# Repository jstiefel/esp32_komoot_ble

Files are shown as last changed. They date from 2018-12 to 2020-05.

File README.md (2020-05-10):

Hint: The code is deprecated and only kept for reference. Only tested with iOS. It won't work if you don't use the mentioned library versions. The official ESP32 Android libraries now include BLE.

# The Komoot BLE Navigation Device Project

The goal of this project is to create an inexpensive turn-by-turn navigation device based on ESP32 and [Komoot's BLE Connect API](https://github.com/komoot/BLEConnect).

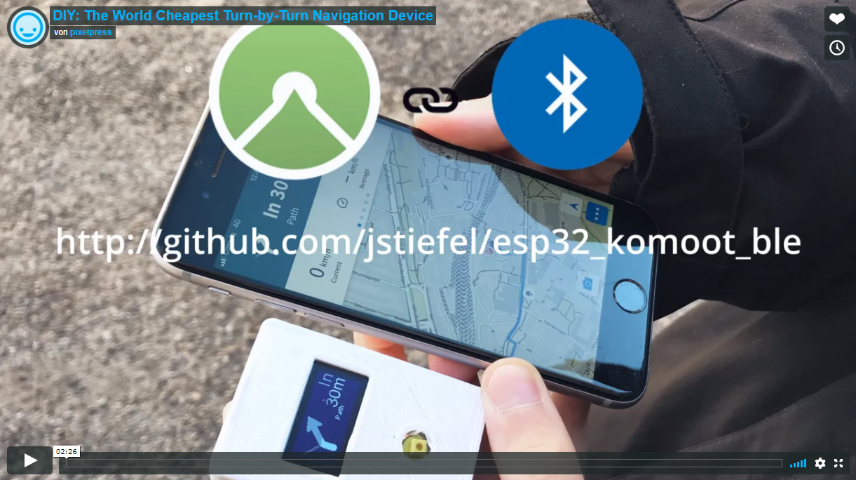
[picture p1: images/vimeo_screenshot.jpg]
DIY: The World Cheapest Turn-by-Turn Navigation Device (https://vimeo.com/308569903 "DIY: The World Cheapest Turn-by-Turn Navigation Device - Click to Watch!")


## Overview

This repository includes all the necessary files to build your own turn-by-turn navigation device including the files for the 3D printable case.

## User instructions
1. The battery can easily be charged by connecting the ESP32 to an USB charger if a controller with battery management is used (e.g. Adafruit Huzzah ESP32).
2. To wake up the device from deep sleep press the button. The welcome screen is shown and ESP32 starts searching for the Komoot BLE service.
3. Open the [Komoot app](https://www.komoot.de/) on your phone and make sure Bluetooth on your phone is turned on. Start your navigation. There is no need to manually connect the ESP32 in the settings. After some seconds, the devices are paired.
4. The device now shows the navigation instructions from the Komoot app. 
5. If connection is lost or navigation stopped, ESP32 tries to keep connection to the device for first 100 seconds. After this, it starts searching for new devices. If no new device is found for the next 100 seconds, it returns to deep sleep.
6. Device can manually be turned off by pushing the button. This takes approximately 2 seconds.

## Status

This is a first prototype which is fully working and tested. New functionality and hardware may be added. The ESP32 is quite new and the Arduino implementation still undergoing many changes. It is recommended to use the same release as stated here because there were many issues with BLE when updating versions.

Next steps:

- improve case/ make smaller
- use larger display
- smoothen images
- add more functionality
- add battery indication
- continuously update used libraries

## Hints

- Device can not be completely turned off without disconnecting battery, but we can enter deep sleep by pushing button and waking up again by pushing same button
- Device can be loaded over USB port (LiPo control on-board)
- Rename main file in .ino to work with Arduino IDE

## Hardware

- Adafruit Huzzah ESP32 (or any other with included battery management)
- 128x64 OLED, SSD1306 Controller
- Push button, some wires and 3D printed case, screws
- 3.7V 400mAh LiPo

## Connections

Display:

| Display | ESP32 |
|---|---|
|SDA|Pin 27|
|SCL|Pin 33|
|VCC|VCC|
|GND|GND|

Button:

| Button | ESP32 |
|---|---|
|In|Pin 32 pulled down with 10kOhm resistor connected to GND|
|Out|VCC|

## Dependencies

- [ESP8266 and ESP32 Oled Driver for SSD1306 display 4.0.0 by Daniel Eichhorn, Fabrice Weinberg](https://github.com/ThingPulse/esp8266-oled-ssd1306)
- [Arduino core for ESP32 WiFi chip v1.0.1-rc1](https://github.com/espressif/arduino-esp32) (development release)
- Replace BLE source code in /opt/eclipse/arduinoPlugin/packages/esp32/hardware/esp32/1.0.1-rc1/libraries/BLE/src by commit _11a0aa6_ of [ESP32_BLE_Arduino](https://github.com/nkolban/ESP32_BLE_Arduino)
- Developped in Eclipse with [Sloeber](https://github.com/Sloeber/arduino-eclipse-plugin)

## Assembly

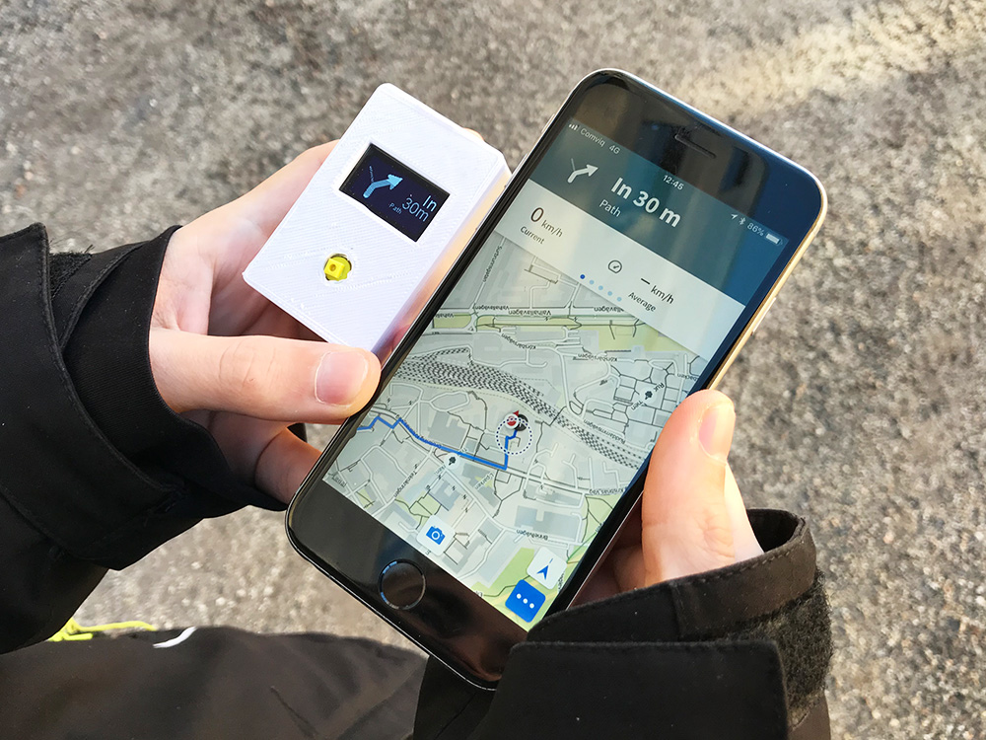
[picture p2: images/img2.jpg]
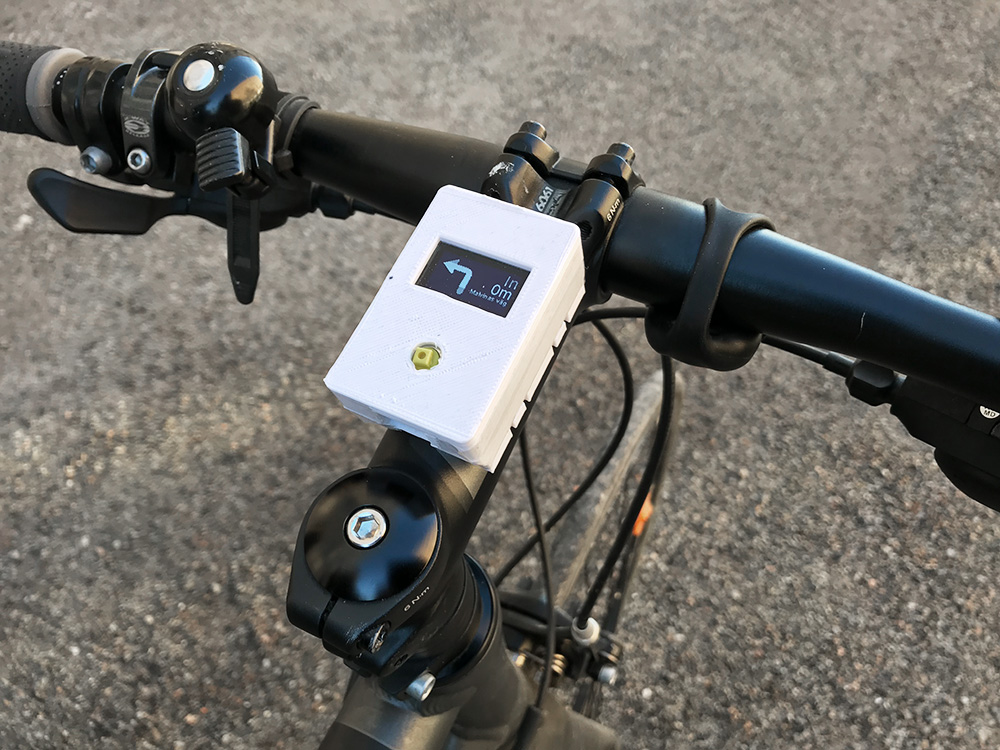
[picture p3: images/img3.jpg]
  <br/>

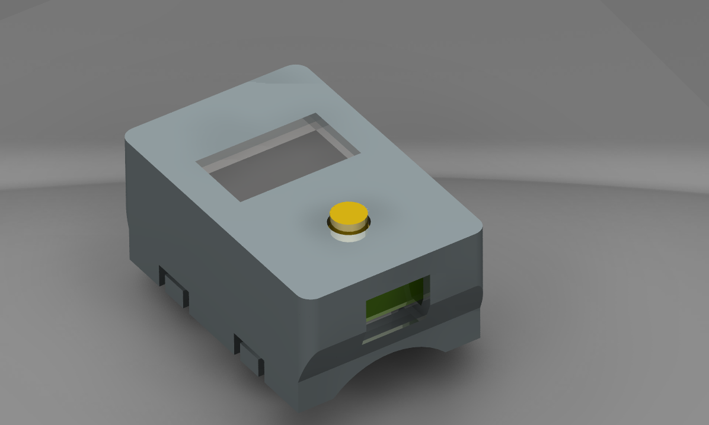
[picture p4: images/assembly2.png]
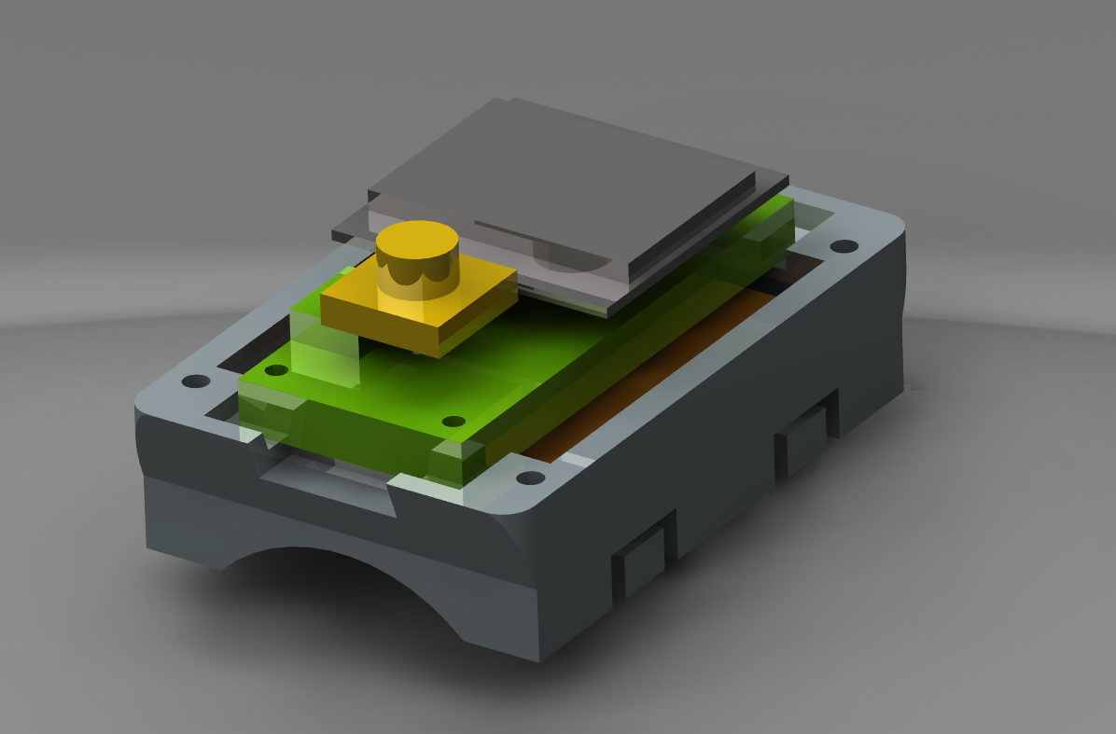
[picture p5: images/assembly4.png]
  <br/>

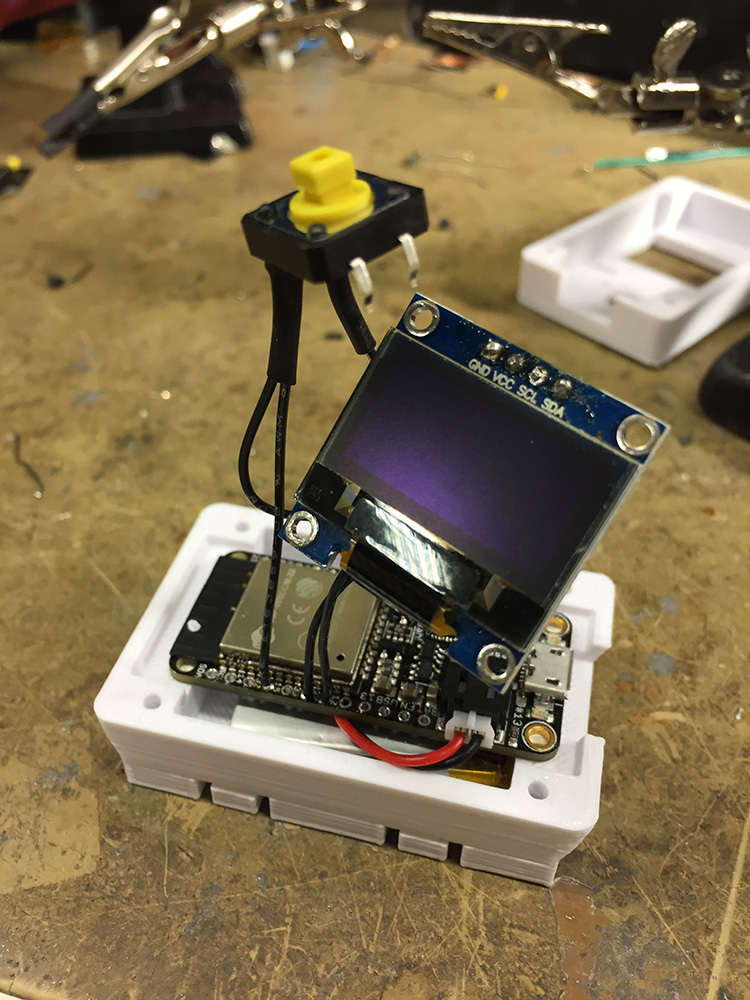
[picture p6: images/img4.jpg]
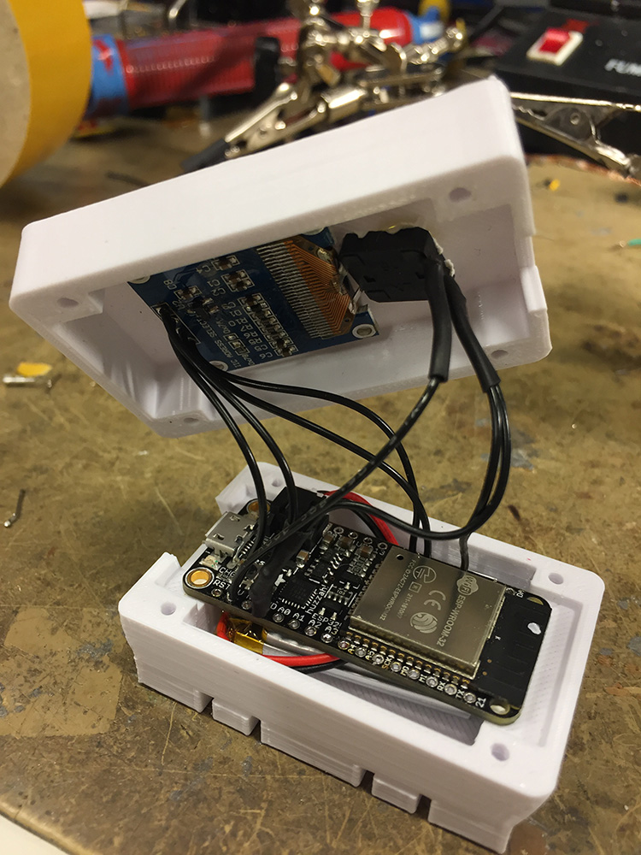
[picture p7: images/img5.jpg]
  

## Credits
- @danielgard for clarifying some things about the Komoot API
- @chegewara for continuously debugging Arduino ESP32 BLE
- Axel Poidevin for carrying the bike and phone in the video

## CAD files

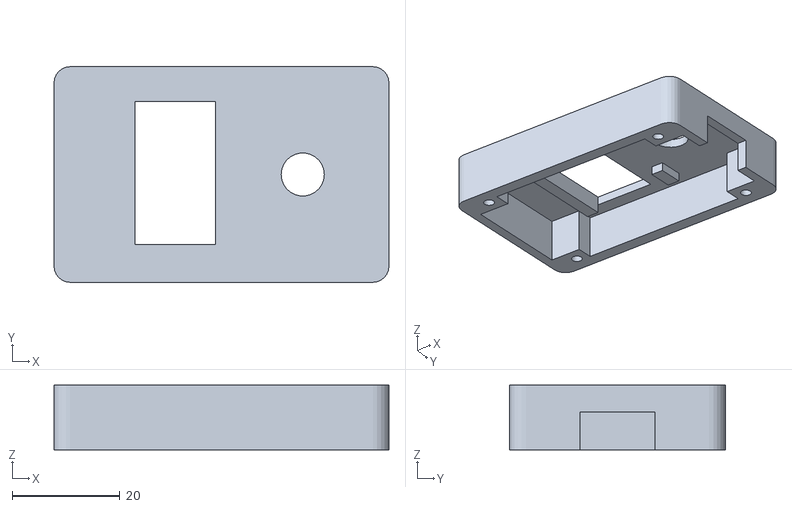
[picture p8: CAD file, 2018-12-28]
CAD/top.stl
62.1 x 40.0 x 12.0

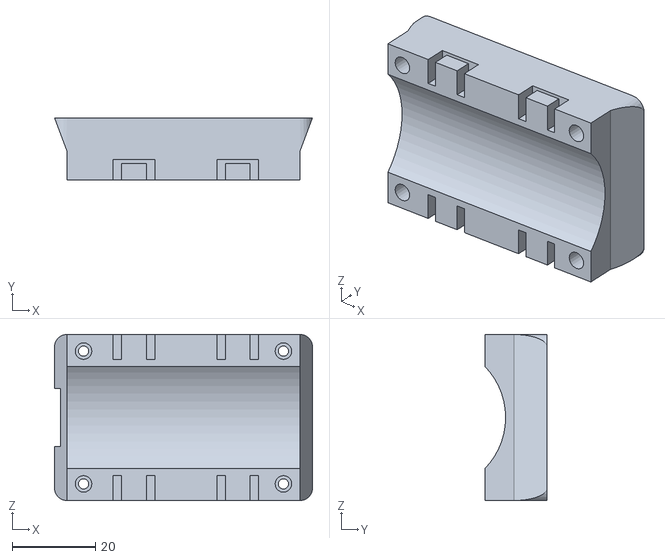
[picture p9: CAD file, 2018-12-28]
CAD/base.stl
62.1 x 15.0 x 40.0

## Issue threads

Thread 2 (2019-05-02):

Kein Problem

Tombo89, 2019-05-02:
Hallo,
gleich vorweg, ich habe kein Problem, wusste aber nicht wie ich sonst kontakt aufnehmen kann.

Ich finde es interessant was du hier geschafft hast. Ich habe vor c.a 1,5 Jahren das gleiche gebaut, doch habe es nie so richtig mit der Bluetooth kommunikation hinbekommen. Ich denke ich werde mir mal deinen code genauer ansehen, da kann ich bestimmt noch was lernen.

Was ich gesehen habe ist das du ein Oled display nutzt. Hattest du bisher damit Probleme bei Sonneneinstrahlung? Ich habe nämlich darmals festegestellt das es bei Sonne nicht wirklich gut lesbar ist und extra high brightness sunlight readable tfts bestellt.

Da es die in den kleinen größen nur bei Digikey gab habe ich um versand zu sparen mehrere bestellt. Wenn du Interesse hast würde ich dir zum testen mal eins abgeben. Die ansteuerung mit dem Esp ist ziemlich simpel und funktioniert ohne Probleme.

Vielen dank schonmal für das veröffentlichen des Codes, den werde ich jetzt erstmal studieren :)

jstiefel, 2019-05-03:
Hallo

Danke! In BLE muss man sich in der Tat ein bisschen einarbeiten. Wichtig ist halt, dass die Hardware den BLE Standard auch unterstützt. Damit fallen etwa die Arduino HC-05/ HC-06 Module sowieso schon aus dem Rennen. Der ESP32 bietet da eine gute Alternative. Aber gerade Ende letzten Jahres war die entsprechende Library auch noch stark in der Entwicklungsphase und es würde mich nicht verwundern, wenn mit der aktuellen Version mein Code nicht mehr läuft. Da wurde schon damals sehr viel geändert. Also unbedingt zum testen die entsprechende Version verwenden.

Habe das OLED Display nicht weiter getestet. Auf jedenfall interessant wäre auch ein E-Ink Display. Du darfst halt die Akku-Laufzeit nicht vergessen. Das könnte vielleicht bei "extra high brightness" zum Problem werden.

Viel Erfolg!

Closed 2019-05-03.

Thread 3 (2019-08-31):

Is this project dead?

coltc50, 2019-08-31:
Hello, great thing you made here. I just ordered all the things and will try to build it. I don't have experience with adafruit at the moment. I just using a lot of arm platines like raspberry or odroid. This thing is new for me. Hope I will get it to work.

Now my question. You maintain this project anymore or is it dead?

I wish a little smaller case but I had the problem that I didn't have a 3d printer.

I will try first to make it working and then I look how I get build a nice case.

Thank you for this great project. It's that what I searched and waiting for so long.

jstiefel, 2019-08-31:
Hi,

Thank you. I currently don't have time to maintain this project. But if you use the versions as mentioned in the Readme, it should still work. Feel free to contribute your model/ code if you want.

coltc50, 2019-09-03:
Thank you. Now I have everything here SD1306 and a ESP32 Feather Board. But I don't know how to start and how to upload your code to the ESP32. Can you give me a hint?

coltc50, 2019-09-04:
Oh hab jetzt erst gesehen das Du auch Deutsch kannst.

Also ich habe es jetzt zumindest mal auf den ESP32 bekommen, aber wenn ich es ausführe und mich verbinde stürzt es ab:

21:41:17.925 -> Wake up!
21:41:17.925 -> Starting Arduino BLE Client application...
21:41:18.535 ->  - Created client
21:41:18.628 -> BLE Advertised Device found: Name: , Address: 3a:9d:15:ad:6f:e8, manufacturer data: 0600010920029f78d337bcfc6c35786a98772a89b35c6295ec36af358a
21:41:18.675 -> BLE Advertised Device found: Name: HUAWEI Mate 9, Address: xx:xx:xx:xx:xx:xx, serviceUUID: safsf-safds-asdfaf-asdfadf-asdfasf
21:41:18.675 -> Found our device!
21:41:18.675 -> Forming a connection to 62:ee:51:30:eb:c0
21:41:18.956 -> onConnect callback: Connected
21:41:18.956 ->  - Connected to server
21:41:19.753 ->  - Found our service
21:41:19.753 ->  - Found our characteristic
21:41:19.753 -> Guru Meditation Error: Core  1 panic'ed (LoadProhibited). Exception was unhandled.
21:41:19.753 -> Core 1 register dump:
21:41:19.753 -> PC      : 0x400d6647  PS      : 0x00060530  A0      : 0x800d1aad  A1      : 0x3ffc8980
21:41:19.753 -> A2      : 0x00000000  A3      : 0x3ffbed90  A4      : 0x00000002  A5      : 0x00000001
21:41:19.753 -> A6      : 0x3ffe0be4  A7      : 0x3f018a00  A8      : 0x800d5d38  A9      : 0x3ffc8930
21:41:19.753 -> A10     : 0x3ffc897c  A11     : 0xc2cfe5f0  A12     : 0x3ffc6338  A13     : 0xc2cfe5f0
21:41:19.800 -> A14     : 0x00000001  A15     : 0x00000038  SAR     : 0x00000018  EXCCAUSE: 0x0000001c
21:41:19.800 -> EXCVADDR: 0x00000030  LBEG    : 0x4000c349  LEND    : 0x4000c36b  LCOUNT  : 0x00000000
21:41:19.800 ->
21:41:19.800 -> Backtrace: 0x400d6647:0x3ffc8980 0x400d1aaa:0x3ffc89b0 0x400d1def:0x3ffc8a00 0x400d1eb3:0x3ffc8a20 0x400d3227:0x3ffc8a60 0x400da40f:0x3ffc8ab0 0x4008e539:0x3ffc8ad0
21:41:19.800 ->
21:41:19.800 -> Rebooting...

coltc50, 2019-09-05:
Ich bekomme deine Libarys nicht in IDE. Unter den Links finde ich auch nicht die RC1 Version.
Ich werde heute Abend einfach Mal mit einem älteren Libary versuchen.

jstiefel, 2019-09-05:
https://github.com/espressif/arduino-esp32/tree/1.0.1-rc1

But it would make sense to adapt to the new release. I just sticked to this version because back then, many changes were going on.

Since the other questions are more general, I would recommend to read into some ESP32 and Arduino tutorials. BLE is not the easiest thing to start with...

coltc50, 2019-09-05:
Ok, thank you to pointing me to it. I manage to load the 1.0.1-rc1 and to change the commit like its explained on the readme but the guru mediation stays:

22:02:12.571 -> Starting Arduino BLE Client application...
22:02:13.192 ->  - Created client
22:02:13.261 -> BLE Advertised Device found: Name: HUAWEI Mate 9, Address: xx:xx:xx:xx:xx, serviceUUID: asd-asd-asd-asd-asd-asd-asd
22:02:13.261 -> Found our device!
22:02:13.261 -> Forming a connection to 6a:52:fe:9e:c5:48
22:02:13.261 -> [I][BLEDevice.cpp:600] addPeerDevice(): add conn_id: 0, GATT role: client
22:02:13.261 -> [W][Connection.cpp:166] my_gattc_event_handler(): custom gattc event handler, event: 0
22:02:13.811 -> [W][Connection.cpp:166] my_gattc_event_handler(): custom gattc event handler, event: 40
22:02:13.811 -> onConnect callback: Connected
22:02:13.811 ->  - Connected to server
22:02:13.811 -> [W][Connection.cpp:166] my_gattc_event_handler(): custom gattc event handler, event: 2
22:02:14.598 -> [W][Connection.cpp:166] my_gattc_event_handler(): custom gattc event handler, event: 7
22:02:14.598 -> [W][Connection.cpp:166] my_gattc_event_handler(): custom gattc event handler, event: 7
22:02:14.598 -> [W][Connection.cpp:166] my_gattc_event_handler(): custom gattc event handler, event: 7
22:02:14.598 -> [W][Connection.cpp:166] my_gattc_event_handler(): custom gattc event handler, event: 7
22:02:14.598 -> [W][Connection.cpp:166] my_gattc_event_handler(): custom gattc event handler, event: 7
22:02:14.598 ->  - Found our service
22:02:14.598 -> [W][Connection.cpp:166] my_gattc_event_handler(): custom gattc event handler, event: 6
22:02:14.668 -> [WGuru Meditation Error: Core  1 panic'ed (LoadProhibited). Exception was unhandled.
22:02:14.668 -> Core 1 register dump:
22:02:14.668 -> PC      : 0x400d6f93  PS      : 0x00060530  A0      : 0x800d1d79  A1      : 0x3ffc99b0
22:02:14.668 -> A2      : 0x00000000  A3      : 0x3ffbed90  A4      : 0x00000002  A5      : 0x00000001
22:02:14.668 -> A6      : 0x3ffe22b4  A7      : 0x3f019a30  A8      : 0x800d65a4  A9      : 0x3ffc9960
22:02:14.668 -> A10     : 0x3ffc99ac  A11     : 0x3ffe22b4  A12     : 0x00000024  A13     : 0xbbc909ee
22:02:14.668 -> A14     : 0x3ffc9960  A15     : 0x00000038  SAR     : 0x0000000a  EXCCAUSE: 0x0000001c
22:02:14.703 -> EXCVADDR: 0x00000030  LBEG    : 0x4000c2e0  LEND    : 0x4000c2f6  LCOUNT  : 0x00000000
22:02:14.703 ->
22:02:14.703 -> Backtrace: 0x400d6f93:0x3ffc99b0 0x400d1d76:0x3ffc99e0 0x400d20bb:0x3ffc9a30 0x400d2197:0x3ffc9a50 0x400d350b:0x3ffc9a90 0x400db77b:0x3ffc9ae0 0x4008e5c9:0x3ffc9b00
22:02:14.703 ->
22:02:14.703 -> Rebooting...
22:02:14.703 -> ets Jun  8 2016 00:22:57
22:02:14.703 ->
22:02:14.703 -> rst:0xc (SW_CPU_RESET),boot:0x13 (SPI_FAST_FLASH_BOOT)
22:02:14.703 -> configsip: 0, SPIWP:0xee
22:02:14.703 -> clk_drv:0x00,q_drv:0x00,d_drv:0x00,cs0_drv:0x00,hd_drv:0x00,wp_drv:0x00
22:02:14.703 -> mode:DIO, clock div:1
22:02:14.703 -> load:0x3fff0018,len:4
22:02:14.703 -> load:0x3fff001c,len:1100
22:02:14.703 -> load:0x40078000,len:9564
22:02:14.703 -> ho 0 tail 12 room 4
22:02:14.703 -> load:0x40080400,len:6348
22:02:14.703 -> entry 0x400806a8

What can I do?

coltc50, 2019-09-05:
Now I also import the mention ssd1306 library in the readme and tried with old komoot version. Problem stays. I'm out of ideas... what I'm doing wrong?

jstiefel, 2019-09-05:
It‘s clearly a BLE problem. You should try to debug by adding serial outputs to the code and find the line where it fails. I honestly never tried with Android.

My recommendation is still to update the BLE library since back then this was a little bit tricky and now it‘s probably much better documented and improved.

Otherwise, if you have a specific error, the developers of the BLE library are normally answering very quickly.
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
coltc50, 2019-09-22:
@thefriedc No you haven't to pair with your phone. But you have to make the changes I mention to connect with a android phone. When you have made the change you can't connect to Iphone anymore. Keep this in mind.

So then you fire up your arduino to search for bluetooth and then you start komoot going to your profile, then settings and then to bluetooth connect and choose "FLYER E-Bike". Now it should connect. You can now go out to start a navigate and it will show on your arduino.

thefriedc, 2019-09-22:
OK - thanks a lot! I will give that a try as soon as possible.

How did you know to choose "FLYER E-Bike"?

coltc50, 2019-09-22:
Did forget where I read it. It was mentioned somwhere on the net. I read your other messages on the other git with kernel panic. Did you changed the ble files like I said before? Without the changes it doesn't work.

Here my post in the ble library explained how to change for android.

https://github.com/nkolban/esp32-snippets/issues/902

thefriedc, 2019-09-23:
Actually, I use Arduino IDE and the BLE library is included in the core
libs there - v 1.0.2
I could not find the lines of code there you mentioned.
My stacktrace is other one as yours. Also BLERemotedescriptor but in the
Method "writeValue".

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

thefriedc, 2019-09-23:
PC: 0x400d4a67: BLERemoteDescriptor::writeValue(unsigned char*, unsigned int, bool) at /Users/chris/Library/Arduino15/packages/esp32/hardware/esp32/1.0.2/libraries/BLE/src/BLERemoteDescriptor.cpp line 131
EXCVADDR: 0x00000030

Decoding stack results
0x400d4a67: BLERemoteDescriptor::writeValue(unsigned char*, unsigned int, bool) at /Users/chris/Library/Arduino15/packages/esp32/hardware/esp32/1.0.2/libraries/BLE/src/BLERemoteDescriptor.cpp line 131
0x400d43cb: BLERemoteCharacteristic::registerForNotify(void (*)(BLERemoteCharacteristic*, unsigned char*, unsigned int, bool), bool) at /Users/chris/Library/Arduino15/packages/esp32/hardware/esp32/1.0.2/libraries/BLE/src/BLERemoteCharacteristic.cpp line 472
0x400d182d: connectToServer(BLEAddress) at /Users/chris/Documents/Arduino/komoot_nav/komoot_nav.ino line 135
0x400d18f2: loop() at /Users/chris/Documents/Arduino/komoot_nav/komoot_nav.ino line 204
0x400d8a51: loopTask(void*) at /Users/chris/Library/Arduino15/packages/esp32/hardware/esp32/1.0.2/cores/esp32/main.cpp line 19
0x4008e425: vPortTaskWrapper at /Users/ficeto/Desktop/ESP32/ESP32/esp-idf-public/components/freertos/port.c line 143

glatteis, 2019-09-30:
I also have this problem, so I created a pull request (issue substitute) in the repository.

coltc50, 2019-10-06:
Now I seem to have the same problem. The connection does work only sometimes. Didn't know what happened. I tried to start from beginning but can't get it to stable. Didn't know if it was a update. Will try and report back if I found the culprit.

glatteis, 2019-10-06:
> Now I seem to have the same problem. The connection does work only sometimes. Didn't know what happened. I tried to start from beginning but can't get it to stable. Didn't know if it was a update. Will try and report back if I found the culprit.

Did you manage to get any callbacks working? If so, can you please tell me what you did? :)
For me it also only connects on the second try every time.

glatteis, 2019-10-06:
Oh, so this is what Komoot said about this:
```
Based on my current knowledge we'll put this into our list of things we'll look into when we do a next iteration on the protocol.
For sure we want the interface being able to be used by as many BLE devices as possible. Adding the descriptor seems to make our interface more compatible to other libraries out there and will most probably an easy thing to for us and most probably will not break the functionality of existing devices using it. But this is something we have to make sure first.
```

coltc50, 2019-10-06:
@glatteis Great to read from komoot. Will hope that they don't need so much time to Implement it.

Yes here also only on the second try. I think something must update between. In begin of september it worked for me without problems.  If I could find what changes till now?

I'm working all the weeks on a new version with 2 displays, rtc timeclock with temperature sensor and a automated switch on. Now I want to integrate the komoot ble thing and it didn't work anymore... What a mess...

coltc50, 2019-10-10:
Ok I found my problem. I had an old library in my data. Deleted all ble librarys and only edit the one in hardware esp32 and now everything is working again.

Great!

kriszhn, 2020-04-02:
guys my app gets connected it sometimes restart and doesn't show any data in the screen.please help me

Closed 2019-09-11.

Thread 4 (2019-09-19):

Komoot BLE Service not found

thefriedc, 2019-09-19:
Hi @jstiefel,

thanks for sharing your project. I had the same idea with an ESP and display laying around at home. After some googling, I found your project.

I got a question according the BLE service scan and am hoping that you can help me out. I am having troubles discovering the Komoot service.

Also when using your code, the ESP32 does not find the Komoot BLE Service.
So my question:
In the Video you use an iPhone. Did you also test your thingy with an Android device?
Did you need to pair your device in the Android settings and was there something you had to configure in the Komoot app for making this work?

I would be really grateful if you could point me in some direction.

Cheers Chris

jstiefel, 2019-09-19:
Hi Chris,

I never tried with an Android phone. But someone just did and here you can find a solution:
https://github.com/jstiefel/esp32_komoot_ble/issues/3#issuecomment-530089381

I'm not sure how this works for Android, but for iPhone there is no need to pair outside the Komoot app (actually, you can't).

Hope this helps!

thefriedc, 2019-09-19:
Thanks a lot for the fast reply!

I mentioned the guy from #3 in a new comment on the issue. Hopefully he can point out the Android specifics with connecting.

Thanks, Chris

jstiefel, 2019-09-19:
Did you take a look at this:

https://github.com/komoot/BLEConnect#pairing-on-android-not-ios

thefriedc, 2019-09-19:
Yes, thanks - the very first thing I read ;)
 The Problem is, that when creating just a BLE client, my Android device cannot even find the ESP32 for pairing.
Also tried with another paired Android device and BLE Scanner app. No Komoot BLE service discovered.

Closed 2019-09-19.

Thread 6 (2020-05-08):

Hat Komoot etwas geändert? bekomme leider Keine Verbindung Hergestellt zur App (IOS)

daveharix, 2020-05-08:
Hey,
ich hoffe es ist ok für Sie, wenn ich auf Deutsch schreibe.
Ich bin seit längerem auf der Suche nach einer Navigationsanzeige mittels ESP32. Zuletzt habe ich mich mit einem ähnlichen Projekt auseinandergesetzt. https://github.com/alexanderlavrushko/BLE-HUD-navigation-ESP32
Dort ist auch eine BLE Kommunikation mit einer Navigations App. Das Ganze lief auch super auf dem ESP32.
Leider wird die App dort nach 7 Tage auf Basisbetrieb umgestellt und die zusätzliche BLE Kommunikation wird eingestellt.
Ich bin dann vor kurzem auf dieses Projekt gestoßen. Tatsächlich sind die Projekte sehr ähnlich, wodurch ich das ganze schnell auf dem ESP32 und dem I2C Display am Laufen hatte.
Zunächst habe ich den Original Code implementiert, aber hier bekomme ich keine Verbindung zur Komoot App hergestellt. Der Code hier war doch für das Iphone gedacht, oder? Ich hatte auch ein paar Abwandlungen für Andorid hier gesehen. Leider ist mein Android Gerät zu alt und ich konnte keine Tests machen.
Zuletzt habe ich den Code von dem ersten Projekt angepasst (das lief soweit ja ganz gut mit dem Iphone und es sind keine großen Änderungen zu machen), aber selbst damit bekomme ich keine Verbindung.
Ich finde mein Gerät aber irgendwie bekomme ich die Verbindung nicht hergestellt. Hat Komoot da vielleicht mittlerweile etwas geändert? Funktioniert der Code bei Ihnen noch?
hier ein Kurzer Ausschnitt von meiner Ausgabe:
_
mdata OK
setup() finished
loop() start
Forming a connection to 51:88:3d:ce:48:af
 - Created client
 - Connected to server
Failed to find our service UUID: 71c1e128-d92f-4fa8-a2b2-0f171db3436c
Error: cannot connect to BLE server in background

_

Vielleicht habe Sie noch einen Tipp.
Würde mich über eine Antwort freuen.

daveharix, 2020-05-09:
Hey,
nur falls hier einer auch nicht weiterkommt. Ich habe bei https://github.com/RpDp-git/komoot-eink-navigator eine kleine Weiterentwicklung gefunden. Dort steht zwar, dass es für Android gedacht ist, aber es funktioniert auch mit IOS.
Ich habe den Code vereinfacht und erstmal eine Serial Ausgabe gemacht.

**In der neuen Komoot App muss man einmal Aktiv die Verbindung Herstellen:**
Profil >Einstellungen >Bluetooth Connect > Flyer E-Bike > Dort wird dann der ESP32 verbunden
Komoot zeigt bei erfolgreicher Verbindung einen Haken hinter Flyer Bike und sagt Verbunden
_(Komoot Version 10.3.8)_
Dann eine Route starten und die Kommunikation beginnt.

```
Starting Arduino BLE Client application...
Starte SCAN
5 Sekunden
BLE Advertised Device found: Name: XXXXX
SETUP END
DO CONNECT
Forming a connection to 77:ef:1d:14:a2:3b
 - Created client
 - Connected to server
 - Found our service
 - Found our characteristic
The characteristic value was: We are now connected to the BLE Server.
Street: Weg
DIR: 2
Direction: 2
Notify callback for characteristic 503dd605-9bcb-4f6e-b235-270a57483026 of data length 4
data: ]q_p
Direction: 2
Direction: 2

```
Scheint alles zu gehen, leider habe ich immer wieder Verbindungsabbrüche, aber das ist auch noch händelbar.
Aber Großes Lob an Sie für die ersten Entwicklungen.

jstiefel, 2020-05-10:
Hey @daveharix

Danke fürs Reinschauen. In der Tat sind die hier verwendeten Libraries schon älter und noch von der Zeit bevor es die offizielle ESP32 BLE Library gab. Es ist also zu erwarten, dass das Projekt so mit der neuen Library nicht mehr funktioniert. Das Komoot Protokoll ist gleich geblieben, um auch weiterhin die früheren Geräte zu unterstützen.

Closed 2020-05-09.

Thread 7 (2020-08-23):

notifyCallback crashes code

a-RN-au-D, 2020-08-23:
Hello, I hope you could help me solve this problem, I've been trying to make your code work, but it seems the esp32 just won't allow me to connect to my phone (android) without crashing the esp32.

I was able to find that the code crashes when it reaches the

`void notifyCallback(BLERemoteCharacteristic* pBLERemoteCharacteristic, uint8_t* pData, size_t length, bool isNotify);`

here is the error message I get, I hope you can help me solve this issue,
thanks

here the error I get, I was able to trace it back to the

```
ets Jun  8 2016 00:22:57

rst:0xc (SW_CPU_RESET),boot:0x13 (SPI_FAST_FLASH_BOOT)
configsip: 0, SPIWP:0xee
clk_drv:0x00,q_drv:0x00,d_drv:0x00,cs0_drv:0x00,hd_drv:0x00,wp_drv:0x00
mode:DIO, clock div:1
load:0x3fff0018,len:4
load:0x3fff001c,len:1216
ho 0 tail 12 room 4
load:0x40078000,len:10864
load:0x40080400,len:6432
entry 0x400806b8
Wake up!
Starting Arduino BLE Client application...
 - Created client
BLE Advertised Device found: Name: , Address: 76:f8:9f:5b:e3:23, manufacturer data: e00000abca3d35d4, serviceUUID: 0000fe9f-0000-1000-8000-00805f9b34fb
BLE Advertised Device found: Name: , Address: f8:08:4f:9a:93:cc, serviceUUID: cbbfe0e1-f7f3-4206-84e0-84cbb3d09dfc
BLE Advertised Device found: Name: , Address: 8c:79:f5:21:0b:ea, manufacturer data: 750042040180608c79f5210bea8e79f5210be901000000000000
BLE Advertised Device found: Name: , Address: 19:a3:0c:ae:8a:b9, serviceUUID: 0000fd6f-0000-1000-8000-00805f9b34fb
BLE Advertised Device found: Name: , Address: 3e:4a:e9:44:66:c5, serviceUUID: 0000fd6f-0000-1000-8000-00805f9b34fb
BLE Advertised Device found: Name: , Address: 40:be:28:d6:0b:de, manufacturer data: 4c0010061d1ed6e0fbe2, txPower: 12
BLE Advertised Device found: Name: , Address: 78:bd:bc:91:d2:70, manufacturer data: 7500420401018178bdbc91d270264b03ccf2fd70000000000000
BLE Advertised Device found: Name: , Address: 0c:c4:d7:aa:f4:6b, serviceUUID: 0000fd6f-0000-1000-8000-00805f9b34fb
BLE Advertised Device found: Name: , Address: 11:5f:82:5e:6a:e7, manufacturer data: 4c0009060307c0a80057
BLE Advertised Device found: Name: , Address: 59:b5:12:55:8f:fa, manufacturer data: 4c001006111e6b59b3dd, txPower: 12
BLE Advertised Device found: Name: , Address: 7e:c8:b6:59:bd:f5, serviceUUID: 0000fd6f-0000-1000-8000-00805f9b34fb
BLE Advertised Device found: Name: , Address: 08:66:98:ba:07:e6, manufacturer data: 4c000f08c00ab3baf400400b10020104, txPower: 12
BLE Advertised Device found: Name: Itsa_mee_arno, Address: 41:09:8f:e0:bb:a8, serviceUUID: 71c1e128-d92f-4fa8-a2b2-0f171db3436c
Found our device!
Forming a connection to 41:09:8f:e0:bb:a8
onConnect callback: Connected
 - Connected to server
 - Found our service
 - Found our characteristic
Guru Meditation Error: Core  1 panic'ed (LoadProhibited). Exception was unhandled.
Core 1 register dump:
PC      : 0x400d6273  PS      : 0x00060530  A0      : 0x800d2191  A1      : 0x3ffc9ce0
A2      : 0x00000000  A3      : 0x3ffbdd64  A4      : 0x00000002  A5      : 0x00000001
A6      : 0x3ffe2b34  A7      : 0x3f019d60  A8      : 0x800d596c  A9      : 0x3ffc9c90
A10     : 0x3ffc9cdc  A11     : 0x3ffe2b34  A12     : 0x00000024  A13     : 0xb6324ea5
A14     : 0x3ffc9c90  A15     : 0x0000002a  SAR     : 0x00000018  EXCCAUSE: 0x0000001c
EXCVADDR: 0x00000030  LBEG    : 0x4000c2e0  LEND    : 0x4000c2f6  LCOUNT  : 0x00000000

ELF file SHA256: 0000000000000000000000000000000000000000000000000000000000000000

Backtrace: 0x400d6273:0x3ffc9ce0 0x400d218e:0x3ffc9d10 0x400d24cb:0x3ffc9d60 0x400d258f:0x3ffc9d80 0x400d2db7:0x3ffc9dc0 0x400da3a6:0x3ffc9e10 0x40092925:0x3ffc9e30

Rebooting...

```

jstiefel, 2020-08-24:
Hi

I'm sorry, but I can't exactly remember what caused such errors. Are you using the exact versions of the libraries I mentioned? I never tested it with Android, but there are some other issues here about Android. I'm thinking about updating the project to the latest ESP32 Arduino BLE libraries later this year.

a-RN-au-D, 2020-08-30:
Hello, thanks for helping, I've tried so many esp32s boards and all of them throw the same error,
so I believe this error comes from the library itself, by all the comment it seems some have been more successful than I was,
I hope to find the error soon 👍

Closed 2020-10-07.

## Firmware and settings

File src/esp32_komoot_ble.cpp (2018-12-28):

/*
 * 	esp32_komoot_ble.cpp
 *
 *	Version: 1.0.0
 *  Created on: Dec 14, 2018
 *  Author: Julian Stiefel
 *  License: BSD 3-Clause
 *  Description: Main file of esp32_komoot_ble Arduino ESP32 software.
 *  Project created in Eclipse Sloeber. Add corresponding libraries and ESP32 library.
 */

#include "esp32_komoot_ble.h"
//create SSD1306 object here and pass a pointer to Display class
SSD1306Wire oled(0x3c, 27, 33); //SDA pin 27, SCL pin 33
Display Display(&oled);

//Deep sleep:
bool _sleep=false;
unsigned long timedelay;

//BLE:
bool doConnect = false;
bool _update = false;
bool _initialConnect = false;
uint8_t pData_old[4];
unsigned long startTime; //Timer to read signal every 5s
unsigned long notifyTimeout; //Timer to check if no notifications anymore
unsigned long deviceTimeout; //Timer to check if we should scan again for other devices

void setup()
{
	//Display setup:
	Display.init();
	Display.drawWelcomeScreen();

	Serial.begin(115200);
	delay(1000);

	//Deep sleep setup:
	_sleep = false;
	esp_sleep_disable_wakeup_source(ESP_SLEEP_WAKEUP_ALL);
	pinMode(32, INPUT_PULLDOWN); //pin 34-39 do not offer internal resistors; This will only work if RTC peripherals
	//are on in sleep, otherwise use 10kOhm external resistor for pull down
	Serial.println("Wake up!");
	attachInterrupt(digitalPinToInterrupt(32), isr, RISING);

	//BLE:
	Serial.println("Starting Arduino BLE Client application...");
	notifyTimeout = millis();
	startTime = millis();
	deviceTimeout = millis();

	BLEDevice::setCustomGattcHandler(my_gattc_event_handler);  // before BLEDevice::init(); to get disconnect reason output

	BLEDevice::init("");

	pClient  = BLEDevice::createClient();
	Serial.println(" - Created client");

	pClient->setClientCallbacks(new MyClientCallback());

	Display.drawConnectionScreen();
	Display.counter=1;
	scan(); //initial scan which has a callback calling connectToServer() if the service is detected
}

void loop()
{
	//Deep sleep:
	if (_sleep && millis()-timedelay>1000){
		Serial.println("Going to sleep now");
		Display.displayOff();
		esp_sleep_enable_ext0_wakeup(GPIO_NUM_32,1); //1 = High, 0 = Low connected to GPIO32
		esp_deep_sleep_start();
	}


	//BLE:

  if(!pClient->isConnected() || (millis()-notifyTimeout) > 5000){
	//if no connection or notifications/navigation stop, we do a proper
	//disconnect and reconnect
	Serial.println("Connection lost or navigation turned off! Reconnecting...");
	pClient->disconnect();
	delay(50);

  //first try to connect to same device (necessary if app in background and we lost connection)
  //if this fails we scan again; it fails. e.g. when there was no initial connection (=no myDevice)
  //After 100s without notifications we scan for new devices even we still have connection

	if ((millis()-deviceTimeout)<100000){
	  //it is checked that we had initial connection and therefore a valid address
	  reconnect(); //uses myDevice from before again, also works in iOS background
	}

	if(!(pClient->isConnected())){
	  Serial.println("Scan again...");
	  //if reconnect was not successful or not executed (>100s), scan again
	  Display.drawConnectionScreen();
	  Display.counter++;
	  scan();
	}

	if ((millis()-deviceTimeout)>200000){
		_sleep=true;
	}
  }

  //to avoid abort we need to check if client is connected before reading or writing characteristics

  //in the worst case we lose connection between checking and reading -> better don't use flag and directly check in if-condition

  //Read characteristic if new data via notified or more than 4s elapsed since last read (to keep connection)
  if(_update && pClient->isConnected()){
	std::string value = pRemoteCharacteristic->readValue(); //this crashes sometimes
	if (value.length()>4){
	  //in case we have update flag but characteristic changed due to navigation stop between
	  std::string street;
	  street = value.substr(9); //this causes abort when there are not at least 9 bytes available
	  Serial.print("Street: ");
	  Serial.println(street.c_str());

	  std::string direction;
	  direction = value.substr(4,4);
	  uint8_t d=direction[0];
	  Serial.print("Direction: ");
	  Serial.println(d);

	  std::string distance;
	  distance = value.substr(5,8);
	  uint32_t dist=distance[0] | distance[1] << 8 | distance[2] << 16 | distance[3] << 24;
	  Serial.print("Distance: ");
	  Serial.println(dist);

	  //Display - show the navigation instruction:
	  Display.drawNavigationScreen(&d, &dist, street.c_str());

	}
	else {
	  Serial.println("Update flag was set but characteristic changed between notify and reading");
	}
	_update=false; //set flag back
  }

  delay(1000); // Delay a second between loops.

}

//Functions down here:

//Deep sleep:
void IRAM_ATTR isr(){
  detachInterrupt(digitalPinToInterrupt(32)); //because later used for wake up
  //setting flag instead to get a little bit of delay
  _sleep=true;
  timedelay=millis();
}

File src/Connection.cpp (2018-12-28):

/*
 * 	Connection.cpp
 *
 *	Version: 1.0.0
 *  Created on: Dec 14, 2018
 *  Author: Julian Stiefel
 *  License: BSD 3-Clause
 *  Description: Functions for Bluetooth BLE communication.
 *
 *  Use ESP32 1.0.1-rc1 development release (choose in Library Manager)
 *  Replace BLE source code in /opt/eclipse/arduinoPlugin/packages/esp32/hardware/esp32/1.0.1-rc1/libraries/BLE/src
 *  by commit 11a0aa6 of ESP32_BLE_Arduino with git clone/ git checkout commithash
 */

#include "Connection.h"

BLEAddress *pServerAddress;
BLEAdvertisedDevice* myDevice;
BLERemoteCharacteristic* pRemoteCharacteristic;
BLEClient* pClient;
uint8_t notificationOff[] = {0x0, 0x0}; //actually not used
uint8_t notificationOn[] = {0x1, 0x0};

void notifyCallback(
  BLERemoteCharacteristic* pBLERemoteCharacteristic,
  uint8_t* pData,
  size_t length,
  bool isNotify) {

  notifyTimeout=millis();
  deviceTimeout=millis();
  //set update flag whenever there is new data available or more than 4s elapsed since last read instruction because komoot will disconnect
  //if no read after 5s -> if this is really the case, we should set to 3s, otherwise we might miss 5s!!
  if(pData[0]!=pData_old[0] || pData[1]!=pData_old[1] || pData[2]!=pData_old[2] || pData[3]!=pData_old[3] || (millis()-startTime) >=3000){
  _update=true;
  Serial.println("new data");
  memcpy(pData_old, pData, 4);
  startTime=millis();
  //Serial.println("Data changed, Timer reseted!");
  }
}

bool connectToServer() {
    Serial.print("Forming a connection to ");
    Serial.println(myDevice->getAddress().toString().c_str());

    // Connect to the remote BLE Server.
    if(!(pClient->connect(myDevice))){ //if you pass BLEAdvertisedDevice instead of address, it will recognize type of peer device address (public or private)
      Serial.print("Failed to connect to server");
      return false;
    }
    Serial.println(" - Connected to server");

    // Obtain a reference to the service we are after in the remote BLE server.
    BLERemoteService* pRemoteService = pClient->getService(serviceUUID);
    if (pRemoteService == nullptr) {
      Serial.print("Failed to find our service UUID: ");
      Serial.println(serviceUUID.toString().c_str());
      pClient->disconnect();
      delay(50);
      return false;
    }
    Serial.println(" - Found our service");


    // Obtain a reference to the characteristic in the service of the remote BLE server.
    pRemoteCharacteristic = pRemoteService->getCharacteristic(charUUID);
    if (pRemoteCharacteristic == nullptr) {
      Serial.print("Failed to find our characteristic UUID: ");
      Serial.println(charUUID.toString().c_str());
      pClient->disconnect();
      delay(50);
      return false;
    }
    Serial.println(" - Found our characteristic");

    startTime = millis();
    notifyTimeout = millis();

    //descriptor obviously needs to be written first. Should be changed in future versions to happen
    //in registerForNotify function!
    pRemoteCharacteristic->getDescriptor(BLEUUID((uint16_t)0x2902))->writeValue((uint8_t*)notificationOn, 2, true);
    pRemoteCharacteristic->registerForNotify(notifyCallback);
    return true;
}

void scan(){

  // Retrieve a Scanner and set the callback we want to use to be informed when we
  // have detected a new device.  Specify that we want active scanning and start the
  // scan to run for 5 seconds.
  BLEScan* pBLEScan = BLEDevice::getScan();
  pBLEScan->setAdvertisedDeviceCallbacks(new MyAdvertisedDeviceCallbacks());
  pBLEScan->setInterval(1349);
  pBLEScan->setWindow(449);
  pBLEScan->setActiveScan(true);
  pBLEScan->start(5, false);

  connect();
}

bool reconnect(){
    if(_initialConnect==true){
      //same as connectToServer, but with different print outputs
        Serial.print("Reconnecting to ");
        Serial.println(myDevice->getAddress().toString().c_str());

        // Connect to the remote BLE Server.
        if(!(pClient->connect(myDevice))){ //if you pass BLEAdvertisedDevice instead of address, it will recognize type of peer device address (public or private)
          Serial.print("Failed to connect to server again");
          return false;
        }
        Serial.println(" - Connected to server again");

        // Obtain a reference to the service we are after in the remote BLE server.
        BLERemoteService* pRemoteService = pClient->getService(serviceUUID);
        if (pRemoteService == nullptr) {
          Serial.print("Failed to find our service UUID again: ");
          Serial.println(serviceUUID.toString().c_str());
          pClient->disconnect();
          delay(50);
          return false;
        }
        Serial.println(" - Found our service again");


        // Obtain a reference to the characteristic in the service of the remote BLE server.
        pRemoteCharacteristic = pRemoteService->getCharacteristic(charUUID);
        if (pRemoteCharacteristic == nullptr) {
          Serial.print("Failed to find our characteristic UUID again: ");
          Serial.println(charUUID.toString().c_str());
          pClient->disconnect();
          delay(50);
          return false;
        }
        Serial.println(" - Found our characteristic again");

        startTime = millis();
        notifyTimeout = millis();

        //descriptor obviously needs to be written first. Should be changed in future versions to happen
        //in registerForNotify function!
        pRemoteCharacteristic->getDescriptor(BLEUUID((uint16_t)0x2902))->writeValue((uint8_t*)notificationOn, 2, true);
        pRemoteCharacteristic->registerForNotify(notifyCallback);
    }
    return true;
}

void connect(){
  if (doConnect == true){
    //this function can also be called independent of scan (save energy), but a previous scan is necessary
    //to have myDevice. If we want to connect to the same server device again and we assume that
    //nothing has changed, we can directly call connectToServer().
    if (connectToServer()) {
      Serial.println("We are now connected to the BLE Server.");
      _initialConnect=true;
    } else {
      Serial.println("We have failed to connect to the server.");
    }
    doConnect = false;
  }
}

// before setup(), to get disconnect reason outputs
void my_gattc_event_handler(esp_gattc_cb_event_t event, esp_gatt_if_t gattc_if, esp_ble_gattc_cb_param_t* param) {
  ESP_LOGW(LOG_TAG, "custom gattc event handler, event: %d", (uint8_t)event);
        if(event == ESP_GATTC_DISCONNECT_EVT) {
                Serial.print("Disconnect reason: ");
                Serial.println((int)param->disconnect.reason);
        }
}

//class member functions of MyClientCallback:
void MyClientCallback::onConnect(BLEClient* pClient){
  Serial.println("onConnect callback: Connected");
}

void MyClientCallback::onDisconnect(BLEClient* pClient){
  Serial.println("onDisconnect callback: Disconnected");
}
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
